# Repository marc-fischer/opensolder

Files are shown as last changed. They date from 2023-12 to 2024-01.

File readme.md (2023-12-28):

# Marcs OpenSolder
Fully open source JBC T245-compatible soldering station and tool holder, forked from [howie-j's opensolder](https://github.com/howie-j/opensolder)


## Introduction
When looking to buy a genuine JBC station to replace my dated ERSA icon Pico I've came across howie-j's opensolder. That was already pretty close to my requirements, so i forked this repo. 

## Goals:
- _T12 clone_ form factor that does not take up valuable bench space
- Optional USB connection to PID tune and compensate offsets
- Add a tag-connect debug connector 
- Add a I2C to the breakout to be able to extend functionality afterwards (ie. desolder station)
- JBC T245 tip compatibility, with similar performance to the original station
- QoL features that the CDB station have, like auto standby, tip remover, holder, tip cleaner etc.
- Simple design using cheap off-the-shelf parts
- A compact handpiece stand with these features:
	- Detection when the handpiece is in the tool holder (auto standby)
	- Detection when you're about to swap tips (cut power)
	- Integrated tip remover, tip storage, tip cleaner and a soldering wire spool holder
	- Simple to build

## Design Specifications
- 24V toroidal transformer
- Zero Crossing AC switching
- OLED display and rotary encoder for adjusting temperature
- Compact and low profile design
- Super fast heatup time (~4s)
- Hardware should be mostly 3D printable, and easy to build using regular tools

## Station
  
The station is built in a Hammond enclosure, with a center mounted transformer. The PCB is mounted to the custom front panel, and all 230VAC connections is in the rear of the chassis.
There is two connectors on the rear panel, one for connecting to the stand, and an optional ST-link connector for firmware upgrades.

## Stand
  
The stand is made of 3D-printed parts, a genuine JBC tool holder, a tip remover made from aluminium angle and some fasteners. Most parts can be made from aluminium sheet if that is preferred.

## Schematic
This is the internal connections of the JBC C245 cartridge:  
  

[__The schematic__](https://github.com/howie-j/OpenSolder/raw/main/hardware/schematic.pdf) is divided into three sheets: AC, Analog and MCU.

### AC
The 24VAC input is fused, then connected directly to the tip center pin (5). Switching is done with two N-channel mosfets, driven by a Si8751 isolated gate driver.

Zero cross detection is done with an AC optocoupler, and the current is limited by three 10k resistors (to reduce BOM items). This solution triggers the ZeroCross about 90uS prematurely, and that is compensated for in firmware.

The MCU and thermocouple frontend must be electrically isolated, and a 24V to 5V DCDC PSU module solves that problem. The DCDC-supply is preregulated with a 24V linear regulator, and post-regulated to 3.3V with a LDO. This power supply chain is in need of some simplification, but the components are few and cheap, and it works great for now.

### Analog
The thermocouple signal is amplified with a MAX4238 chopper opamp, with a fairly arbitrary amplification of 221, since temperature calibration is done in firmware anyway. No negative supply rail means the thermocouple can't sense lower temperatures than room temp, but that's not needed for a soldering station.

Long handpiece wires means lots of crosstalk, so a pair of diodes clamps the thermocouple input at Vf. The MCU pin _TIP_CLAMP_ is driven low when power is applied to the handpiece, to clamp noise on the opamp input. When its time to measure tip temperature, the pin is set to input, and a delay waits for the RC filter to stabilize.

To sense if there is a tip cartridge in the handpiece, _TIP_CHECK_ is driven high. The low impedance of the thermocouple + heater (a few Ω's) will create a very low voltage drop. If the tip is removed, the Vf of the input protection diode will drive _THERMOCOUPLE_ADC_ close to 3.3V.

### MCU
A STM32F072 is used since I have a few of them in stock, but almost any STM32 could be adapted to work. To sense PCB temperature (and for cold junction compensation), an I2C temp sensor is added. The MCU might have an internal temperature sensor, but  have not looked into that yet.

The rotary encoder and handpiece stand inputs are filtered using plain RC filters. This, combined with the input hysteresis, removes most input noise. The TIM encoder inputs also have additional filtering and FSM redundancy.

## PCB
[___Check out this interactive BOM___](http://htmlpreview.github.io/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)

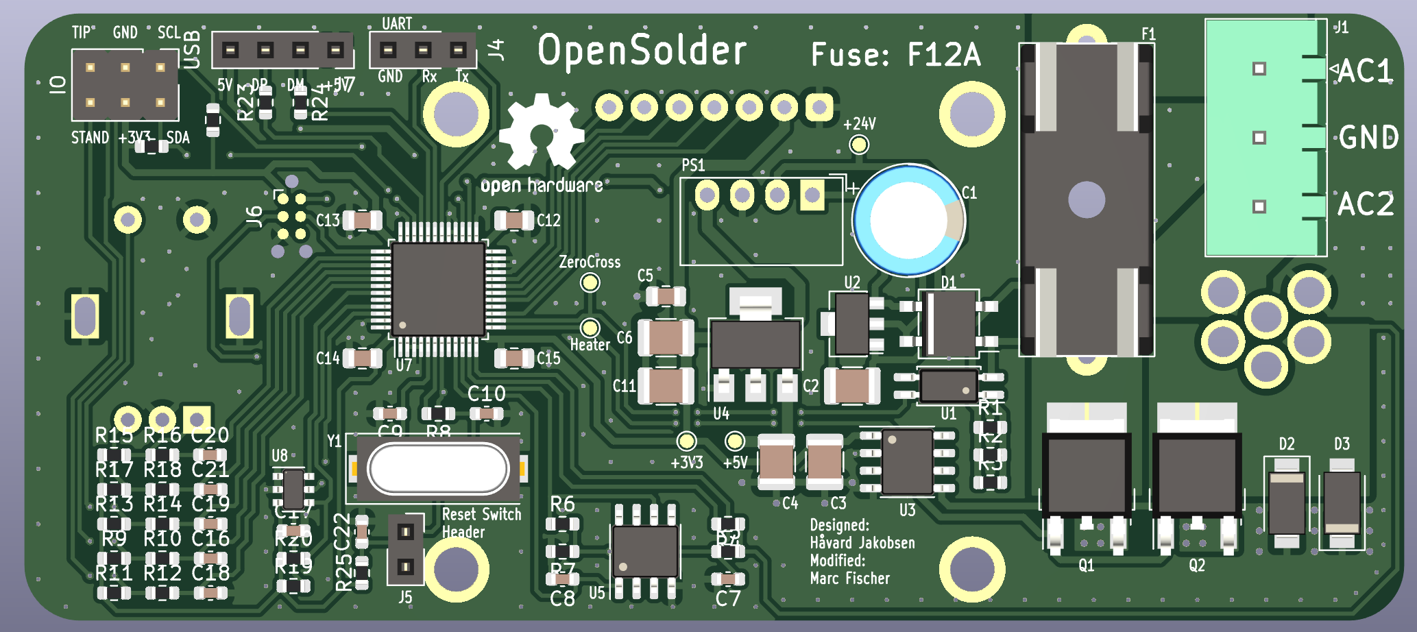
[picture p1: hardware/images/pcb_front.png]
  
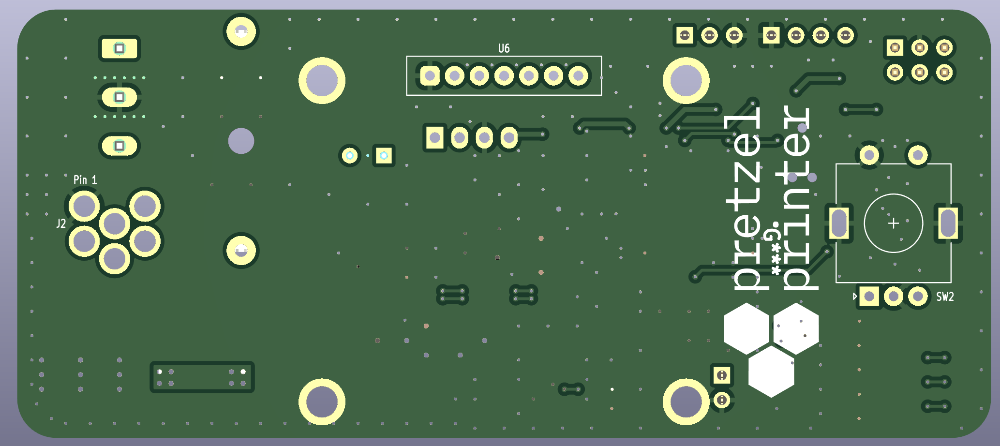
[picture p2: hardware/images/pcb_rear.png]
  
The PCB is quite low density, uses 0603 SMD components and is fully hand solderable with a microscope. Connections to the rear connectors (stand and I2C-2 breakout) is done via a 6-pin IDC connector, so no crimping of tiny connector pins are necessary. The PCB is mounted to the front panel via the rotary encoder and the handpiece connector.

## Firmware
The firmware is simple and functional, and uses a modified hysteresis temperature controller that is very fast but has some initial overshoot. Currently all default values are set in _opensolder.h_, and are reset when the station is powered off.

### TODO
Nothing is currently missing for regular functionality. However some features would be cool to have:

- More accurate temp control (PID or other controller)
- User changeable default values
- Menu for changing default values
- Better looking UI

## Links and Sources
[The unisolder project](https://github.com/sparkybg/UniSolder-5.2) 
[Marco Reps](https://youtu.be/GYIiOkr6x9o) 
[foldvarid93's JBC Soldering Station](https://github.com/foldvarid93/JBC_SolderingStation) 
[johnmx's eevblog thread](https://eevblog.com/forum/testgear/jbc-soldering-station-cd-2bc-complete-schematic-analysis/) 
[howie-j's opensolder](https://github.com/howie-j/opensolder)

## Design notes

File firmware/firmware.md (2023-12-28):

# Do not use this firmware. (yet) 

Work in Progress without possibility to test. I'm still waiting for hardware.

### Installation

Install STM32CubeIDE, click "Open project from filesystem" and select the "opensolder" folder.

### Code structure
All cube-generated files are untouched, except for calling opensolder_init() and opensolder_main() in main.c.
- opensolder.c is the "main" file, containing the init calls, superloop and state machine
- opensolder.h contains most constants for easy editing
- tip_temperature.c handles interrupts, does temperature control, adc reading, tip check and such
- gui.c contains all functions to draw graphics to the OLED display

There is a fair bit of comments in the code, and better documentation can be provided if requested. If you have a question or see an issue, just open an issue in this repo.

The tip temperature (heater control) loop happens interrupt-based on a AC alternation (zero-cross). The two-point regulator disables power and enables power depending if the iron should heat or not.

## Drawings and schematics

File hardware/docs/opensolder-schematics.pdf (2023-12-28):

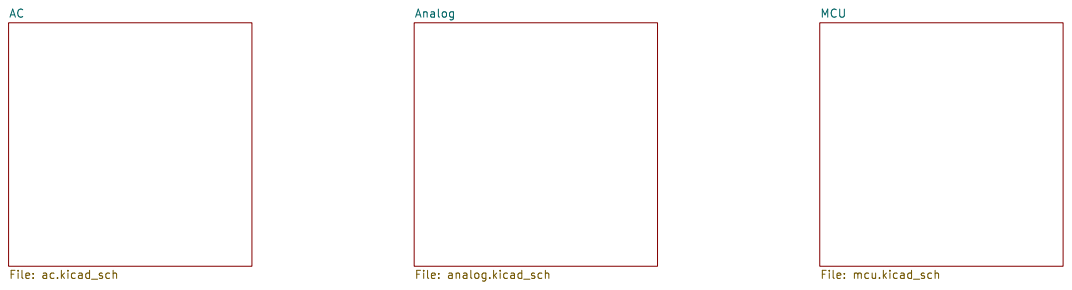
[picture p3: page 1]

File: mcu.kicad_sch Analog File: analog.kicad_sch

Id: 1/4 Title: Marcs OpenSolder Station Schematic

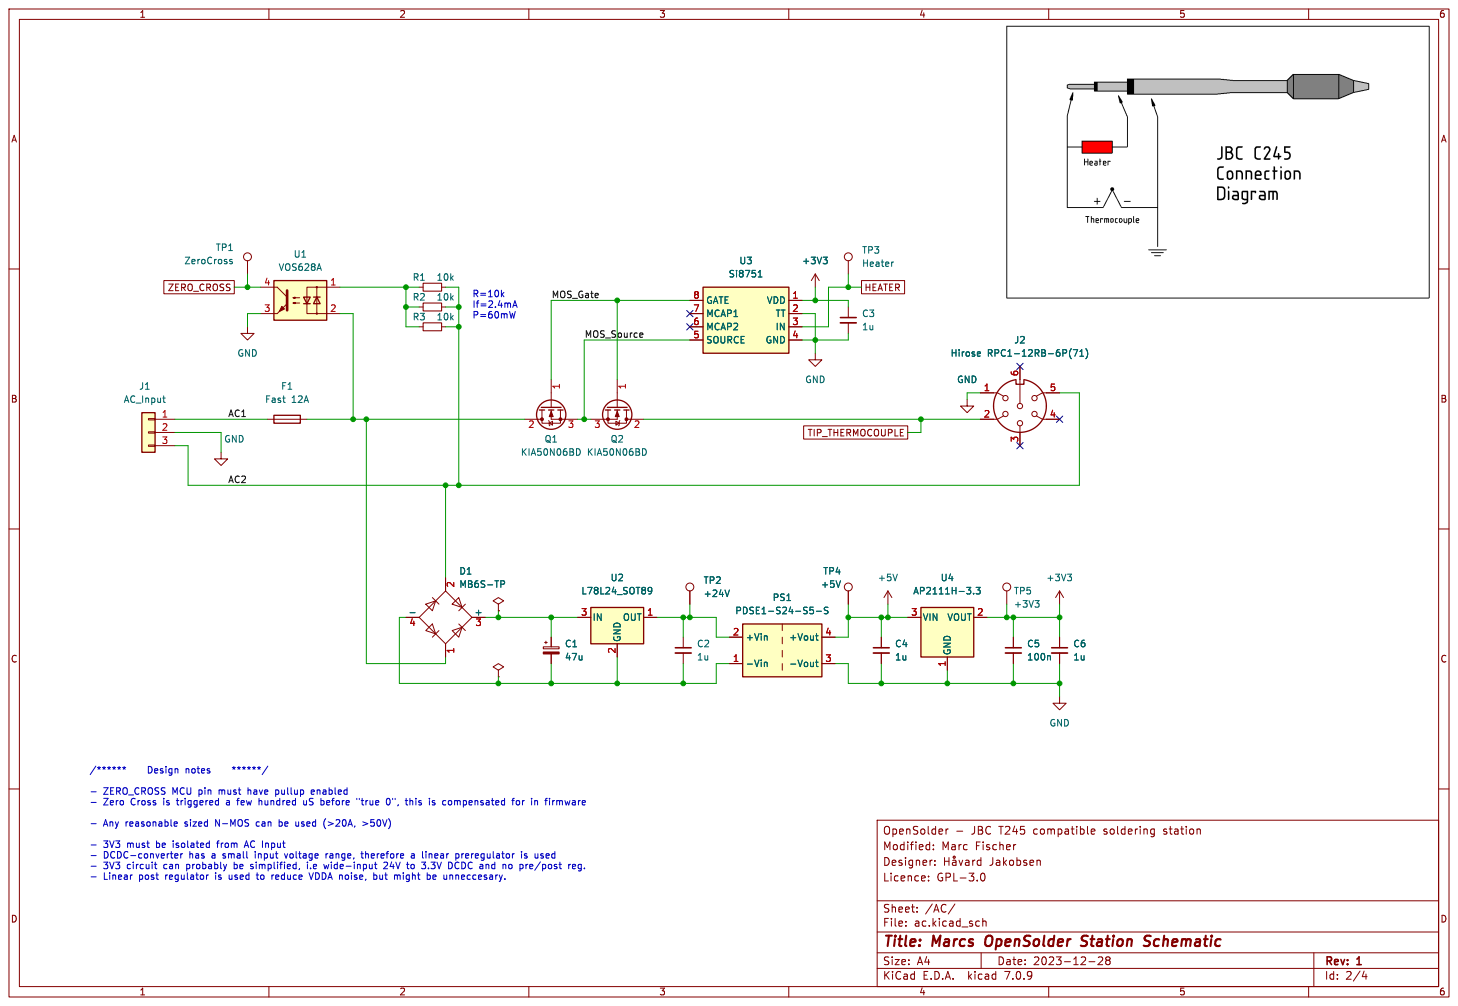
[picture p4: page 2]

1 VOUT 2 VIN 3 U4 AP2111H-3.3 R1 10k TP1 ZeroCross GND GND GND

Id: 2/4 Title: Marcs OpenSolder Station Schematic

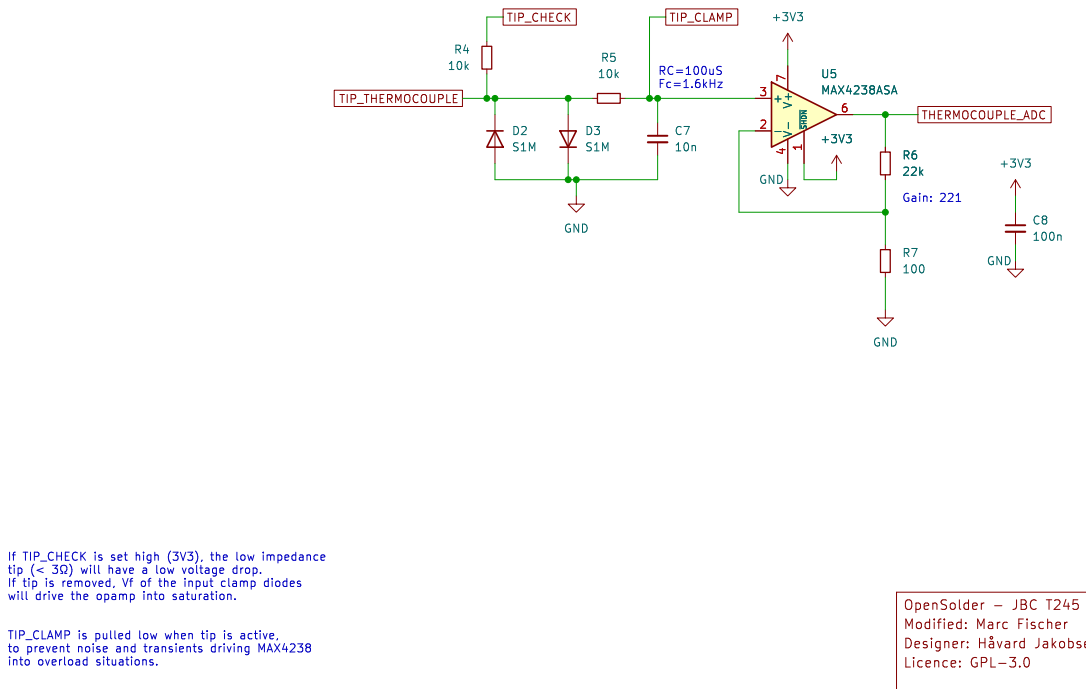
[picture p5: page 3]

If TIP_CHECK is set high (3V3), the low impedance
tip (< þÿ3©) will have a low voltage drop.
If tip is removed, Vf of the input clamp diodes will drive the opamp into saturation. TIP_CLAMP is pulled low when tip is active,

Id: 3/4 Title: Marcs OpenSolder Station Schematic

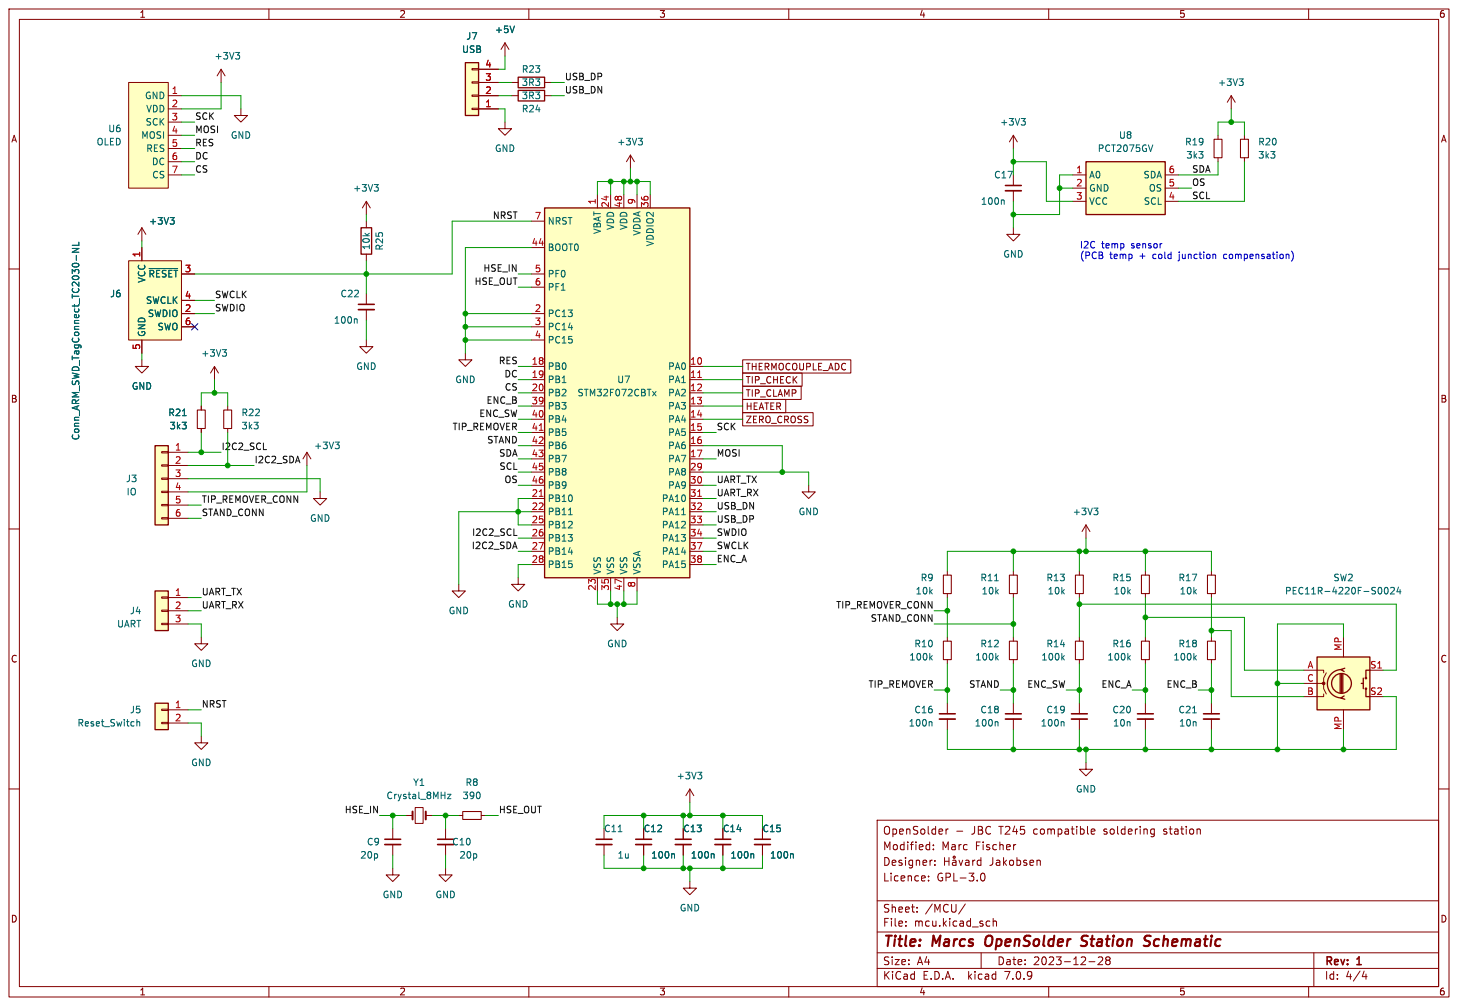
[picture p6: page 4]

1 PA0 10 PA1 11 PA2 12 PA3 13 PA4 14 PA5 15 PA6 16 PA7 17 PB0 18 PB1 19 PC13 2 PB2 20 PB10 21 PB11 22 VSS 23 VDD 24 PB12 25 PB13 26 PB14 27 PB15 28 PA8 29 PC14 3 PA9 30 PA10 31 PA11 32 PA12 33 PA13 34 VSS 35 VDDIO2 36 PA14 37 PA15 38 PB3 39 PC15 4 PB4 40 PB5 41 PB6 42 PB7 43 BOOT0 44 PB8 45 PB9 46 VSS 47 VDD 48 PF0 5 PF1 6 NRST 7 VSSA

1 SWDIO 2 ~{RESET}3 SWCLK 4 GND

Id: 4/4 Title: Marcs OpenSolder Station Schematic

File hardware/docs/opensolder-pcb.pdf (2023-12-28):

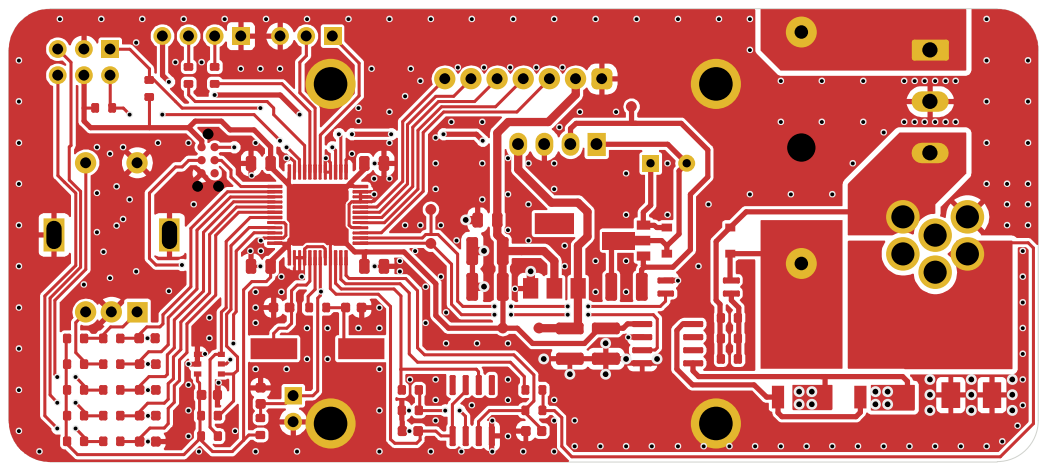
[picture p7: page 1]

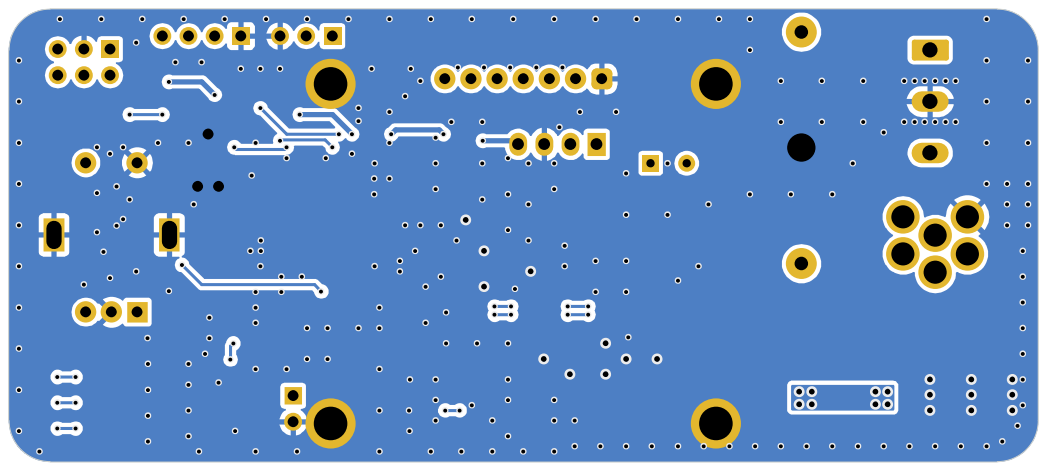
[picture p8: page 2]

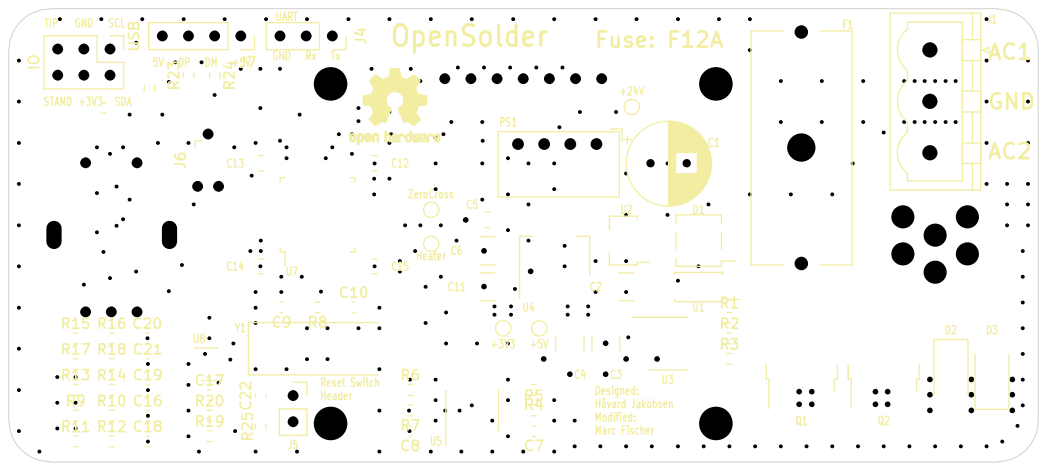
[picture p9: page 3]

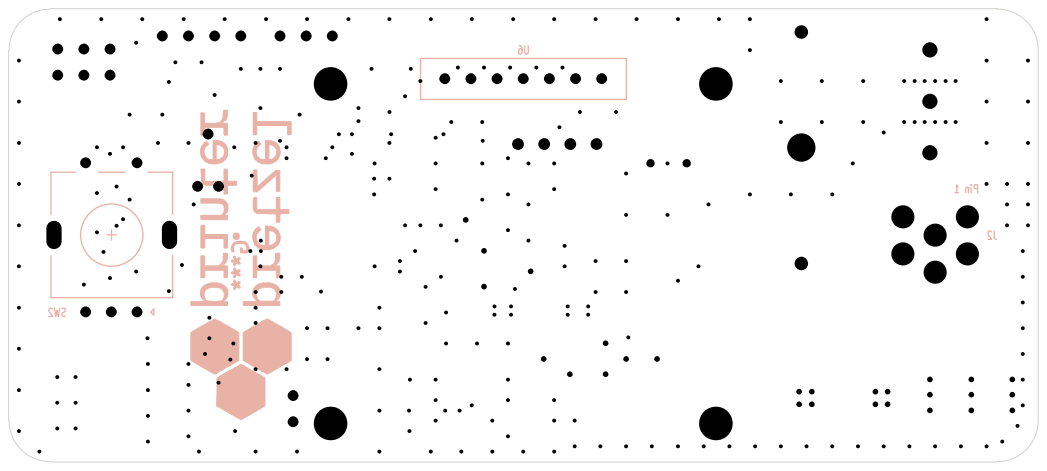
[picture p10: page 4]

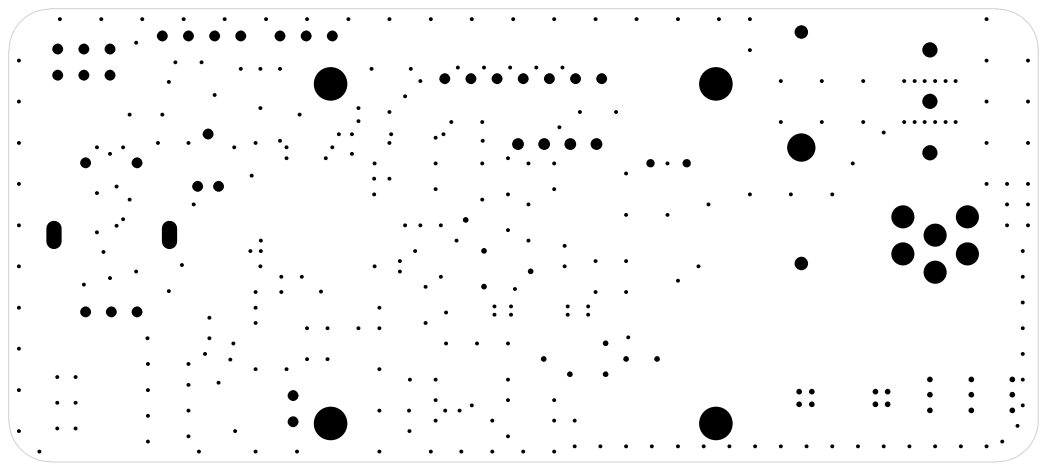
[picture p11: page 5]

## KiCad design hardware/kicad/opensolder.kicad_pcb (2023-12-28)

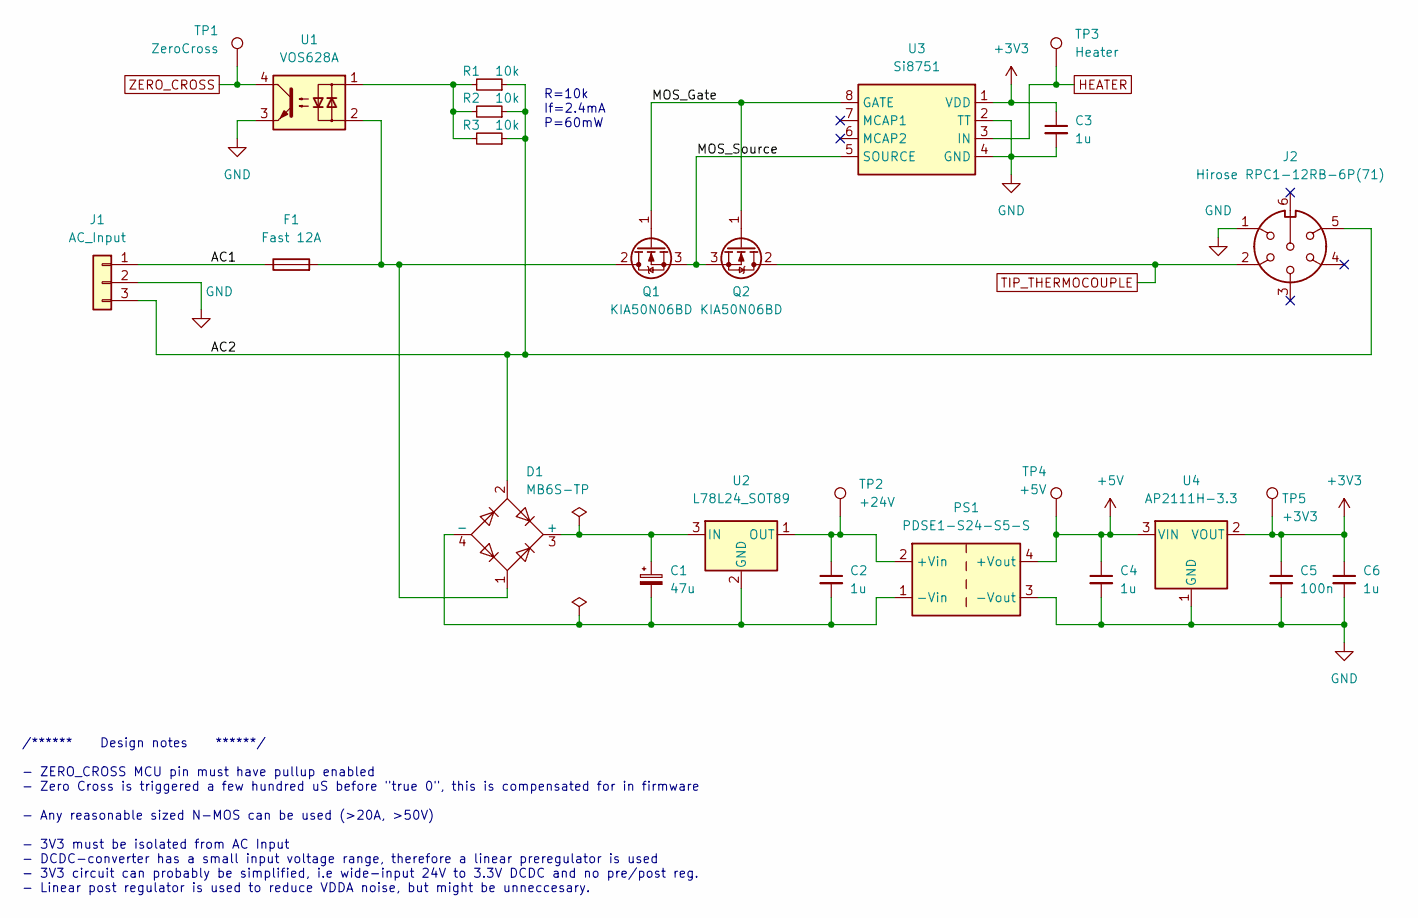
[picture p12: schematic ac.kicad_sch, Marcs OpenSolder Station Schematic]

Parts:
C1: 47u; CP_Radial_D8.0mm_P3.50mm
C2, C3, C4, C6: 1u; C_1210_3225Metric
C5: 100n; C_0805_2012Metric
D1: MB6S-TP; TO-269AA
F1: Fast 12A; Fuseholder_Cylinder-5x20mm_Schurter_0031_8201_Horizontal_Op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
J1: AC_Input; PhoenixContact_MSTBVA_2,5_3-G_1x03_P5.00mm_Vertical
J2: Hirose RPC1-12RB-6P(71); Hirose_RPC1
PS1: PDSE1-S24-S5-S; PDSE1_DCDC
Q1, Q2: KIA50N06BD; TO-252-2
R1, R2, R3: 10k; R_0603_1608Metric
TP1: ZeroCross; TestPoint_Pad_D1.0mm
TP2: +24V; TestPoint_Pad_D1.0mm
TP3: Heater; TestPoint_Pad_D1.0mm
TP4: +5V; TestPoint_Pad_D1.0mm
TP5: +3V3; TestPoint_Pad_D1.0mm
U1: VOS628A; SOP-4_4.4x2.6mm_P1.27mm
U2: L78L24_SOT89; SOT-89-3
U3: Si8751; SOIC-8_3.9x4.9mm_P1.27mm
U4: AP2111H-3.3; SOT-223

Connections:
+3V3: C3.1, C5.1, C6.1, TP5.1, U3.1 (VDD), U4.2 (VOUT); also elsewhere on the board
+5V: C4.1, PS1.4 (+Vout), TP4.1, U4.3 (VIN); also elsewhere on the board
/AC/AC1: F1.1, J1.1
/AC/AC2: D1.2, J1.3, J2.5, R1.1, R2.1, R3.1
/AC/MOS_Gate: Q1.1 (G), Q2.1 (G), U3.8 (GATE)
/AC/MOS_Source: Q1.3 (S), Q2.3 (S), U3.5 (SOURCE)
GND: C3.2, C4.2, C5.2, C6.2, J1.2, J2.1, PS1.3 (-Vout), U1.3, U3.2 (TT), U3.4 (GND), U4.1 (GND); also elsewhere on the board
HEATER: TP3.1, U3.3 (IN); also elsewhere on the board
unnamed: C1.1, D1.3 (+), U2.3 (IN)
unnamed: C1.2, C2.2, D1.4 (-), PS1.1 (-Vin), U2.2 (GND)
unnamed: C2.1, PS1.2 (+Vin), TP2.1, U2.1 (OUT)
unnamed: D1.1, F1.2, Q1.2 (D), U1.2
unnamed: R1.2, R2.2, R3.2, U1.1
TIP_THERMOCOUPLE: J2.2, Q2.2 (D); also elsewhere on the board
ZERO_CROSS: TP1.1, U1.4; also elsewhere on the board

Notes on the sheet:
R=10k If=2.4mA P=60mW
/****** Design notes ******/ - ZERO_CROSS MCU pin must have pullup enabled - Zero Cross is triggered a few hundred uS before "true 0", this is compensated for in firmware - Any reasonable sized N-MOS can be used (>20A, >50V) - 3V3 must be isolated from AC Input - DCDC-converter has a small input vo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

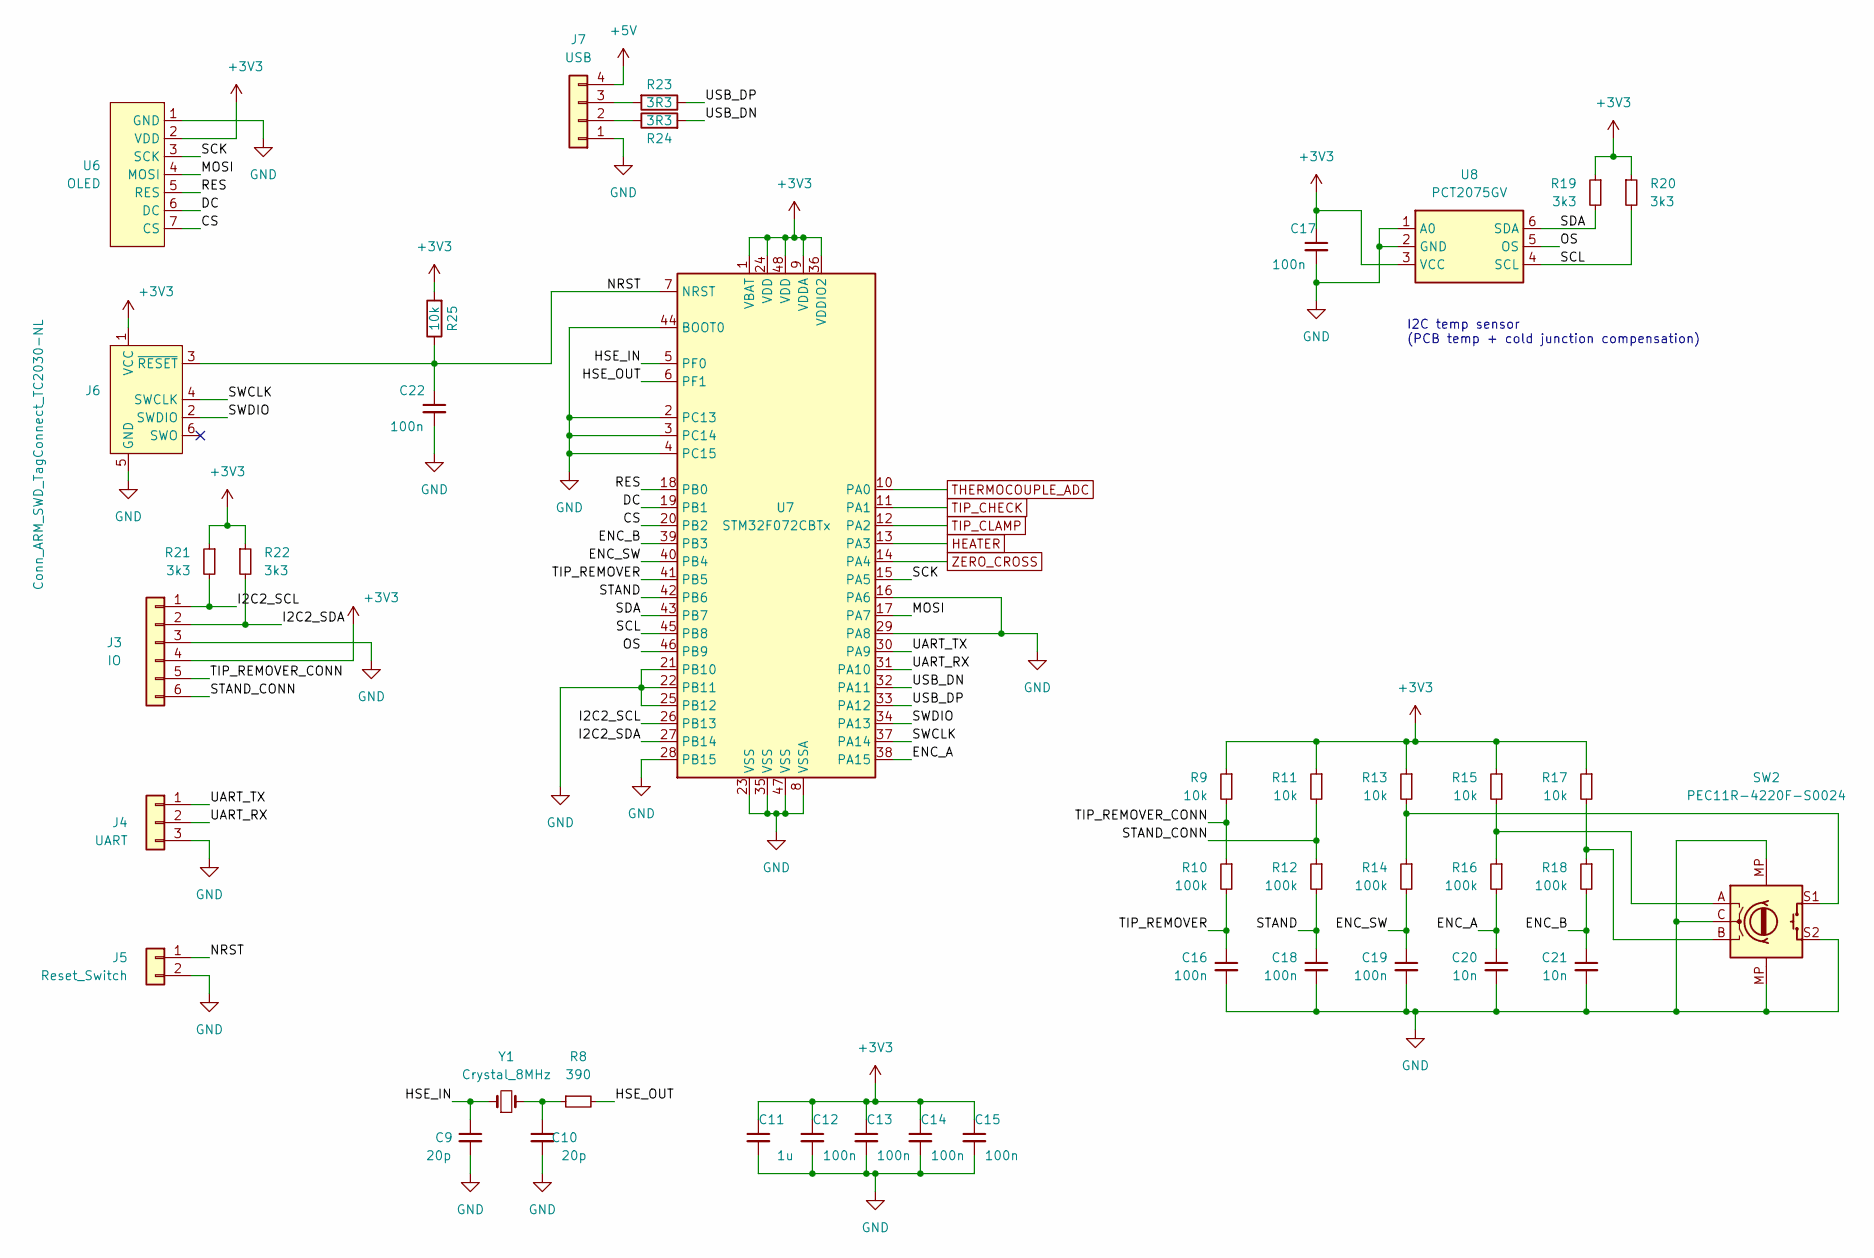
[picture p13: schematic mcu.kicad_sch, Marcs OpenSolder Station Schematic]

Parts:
C9, C10: 20p; C_0603_1608Metric
C11: 1u; C_1210_3225Metric
C12, C13, C14, C15: 100n; C_0805_2012Metric
C16, C17, C18, C19, C22: 100n; C_0603_1608Metric
C20, C21: 10n; C_0603_1608Metric
J3: IO; PinHeader_2x03_P2.54mm_Vertical
J4: UART; PinSocket_1x03_P2.54mm_Vertical
J5: Reset_Switch; PinSocket_1x02_P2.54mm_Vertical
J6: Conn_ARM_SWD_TagConnect_TC2030-NL; Tag-Connect_TC2030-IDC-NL_2x03_P1.27mm_Vertical
J7: USB; PinSocket_1x04_P2.54mm_Vertical
R8: 390; R_0603_1608Metric
R9, R11, R13, R15, R17, R25: 10k; R_0603_1608Metric
R10, R12, R14, R16, R18: 100k; R_0603_1608Metric
R19, R20, R21, R22: 3k3; R_0603_1608Metric
R23, R24: 3R3; R_0603_1608Metric
SW2: PEC11R-4220F-S0024; RotaryEncoder_PEC11R_PEC12R
U6: OLED; OLED_SSD1306_SPI_1.54
U7: STM32F072CBTx; LQFP-48_7x7mm_P0.5mm
U8: PCT2075GV; TSOP-6_1.65x3.05mm_P0.95mm
Y1: Crystal_8MHz; Crystal_SMD_HC49-SD

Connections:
+3V3: C11.1, C12.1, C13.1, C14.1, C15.1, C17.1, J3.4, J6.1 (VCC), R9.1, R11.1, R13.1, R15.1, R17.1, R19.1, R20.1, R21.1, R22.1, R25.2, U6.2 (VDD), U7.1 (VBAT), U7.9 (VDDA), U7.24 (VDD), U7.36 (VDDIO2), U7.48 (VDD), U8.3 (VCC); also elsewhere on the board
+5V: J7.4; also elsewhere on the board
/MCU/CS: U6.7 (CS), U7.20 (PB2)
/MCU/DC: U6.6 (DC), U7.19 (PB1)
/MCU/ENC_A: C20.1, R16.2, U7.38 (PA15)
/MCU/ENC_B: C21.1, R18.2, U7.39 (PB3)
/MCU/ENC_SW: C19.1, R14.2, U7.40 (PB4)
/MCU/HSE_IN: C9.1, U7.5 (PF0), Y1.1
/MCU/HSE_OUT: R8.2, U7.6 (PF1)
/MCU/I2C2_SCL: J3.1, R21.2, U7.26 (PB13)
/MCU/I2C2_SDA: J3.2, R22.2, U7.27 (PB14)
/MCU/MOSI: U6.4 (MOSI), U7.17 (PA7)
/MCU/NRST: C22.1, J5.1, J6.3 (~RESET), R25.1, U7.7 (NRST)
/MCU/OS: U7.46 (PB9), U8.5 (OS)
/MCU/RES: U6.5 (RES), U7.18 (PB0)
/MCU/SCK: U6.3 (SCK), U7.15 (PA5)
/MCU/SCL: R20.2, U7.45 (PB8), U8.4 (SCL)
/MCU/SDA: R19.2, U7.43 (PB7), U8.6 (SDA)
/MCU/STAND: C18.1, R12.2, U7.42 (PB6)
/MCU/STAND_CONN: J3.6, R11.2, R12.1
/MCU/SWCLK: J6.4 (SWCLK), U7.37 (PA14)
/MCU/SWDIO: J6.2 (SWDIO), U7.34 (PA13)
/MCU/TIP_REMOVER: C16.1, R10.2, U7.41 (PB5)
/MCU/TIP_REMOVER_CONN: J3.5, R9.2, R10.1
/MCU/UART_RX: J4.2, U7.31 (PA10)
/MCU/UART_TX: J4.1, U7.30 (PA9)
/MCU/USB_DN: R24.2, U7.32 (PA11)
/MCU/USB_DP: R23.1, U7.33 (PA12)
GND: C9.2, C10.2, C11.2, C12.2, C13.2, C14.2, C15.2, C16.2, C17.2, C18.2, C19.2, C20.2, C21.2, C22.2, J3.3, J4.3, J5.2, J6.5 (GND), J7.1, SW2.C, SW2.MP, SW2.S2, U6.1 (GND), U7.2 (PC13), U7.3 (PC14), U7.4 (PC15), U7.8 (VSSA), U7.16 (PA6), U7.21 (PB10), U7.22 (PB11), U7.23 (VSS), U7.25 (PB12), U7.28 (PB15), U7.29 (PA8), U7.35 (VSS), U7.44 (BOOT0), U7.47 (VSS), U8.1 (A0), U8.2 (GND); also elsewhere on the board
HEATER: U7.13 (PA3); also elsewhere on the board
unnamed: C10.1, R8.1, Y1.2
unnamed: J7.2, R24.1
unnamed: J7.3, R23.2
unnamed: R13.2, R14.1, SW2.S1
unnamed: R15.2, R16.1, SW2.A
unnamed: R17.2, R18.1, SW2.B
THERMOCOUPLE_ADC: U7.10 (PA0); also elsewhere on the board
TIP_CHECK: U7.11 (PA1); also elsewhere on the board
TIP_CLAMP: U7.12 (PA2); also elsewhere on the board
ZERO_CROSS: U7.14 (PA4); also elsewhere on the board

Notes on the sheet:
I2C temp sensor (PCB temp + cold junction compensation)

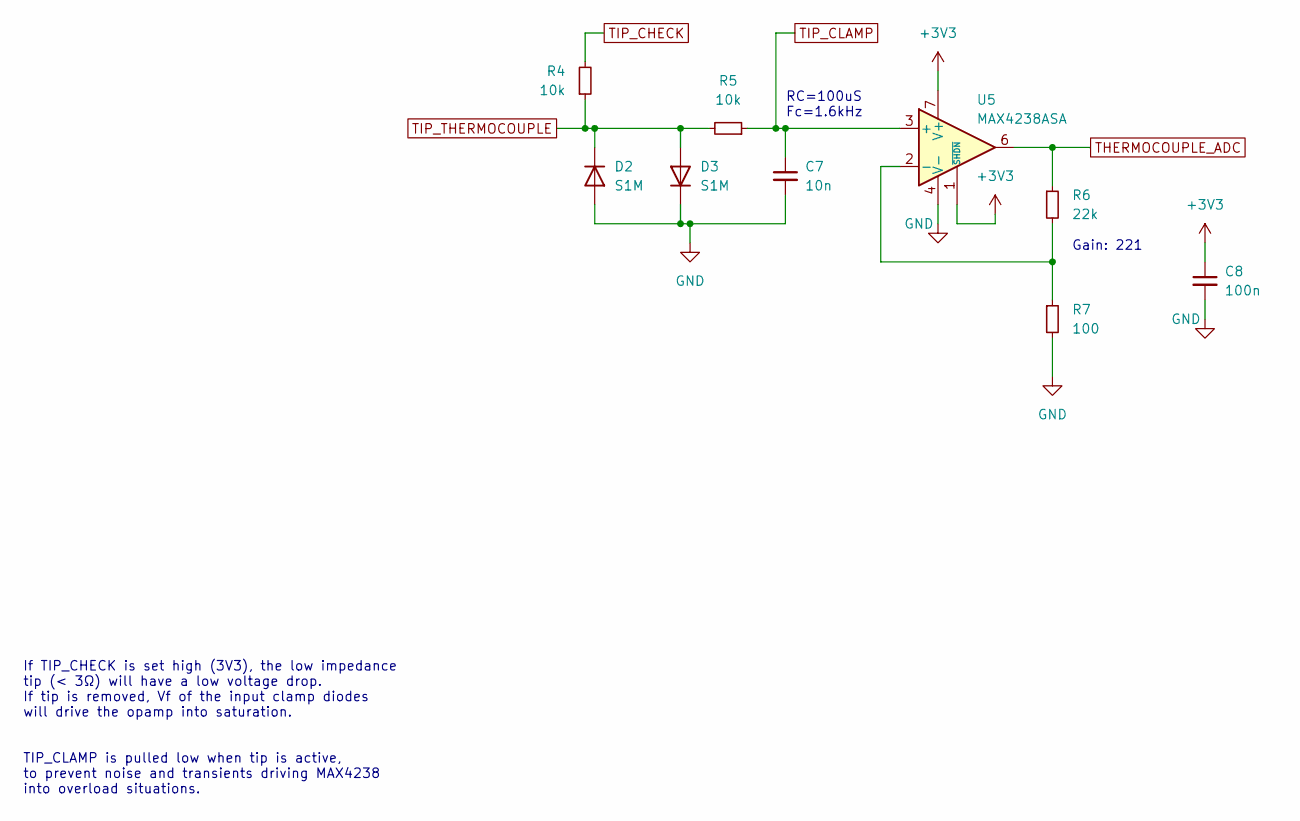
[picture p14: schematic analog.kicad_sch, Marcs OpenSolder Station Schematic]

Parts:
C7: 10n; C_0603_1608Metric
C8: 100n; C_0603_1608Metric
D2, D3: S1M; D_SMA
R4, R5: 10k; R_0603_1608Metric
R6: 22k; R_0603_1608Metric
R7: 100; R_0603_1608Metric
U5: MAX4238ASA; SOIC-8_3.9x4.9mm_P1.27mm

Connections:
+3V3: C8.1, U5.1 (~SHDN), U5.7 (V+); also elsewhere on the board
GND: C7.2, C8.2, D2.2 (A), D3.1 (K), R7.2, U5.4 (V-); also elsewhere on the board
unnamed: R6.2, R7.1, U5.2 (-)
THERMOCOUPLE_ADC: R6.1, U5.6; also elsewhere on the board
TIP_CHECK: R4.2; also elsewhere on the board
TIP_CLAMP: C7.1, R5.1, U5.3 (+); also elsewhere on the board
TIP_THERMOCOUPLE: D2.1 (K), D3.2 (A), R4.1, R5.2; also elsewhere on the board

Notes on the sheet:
Gain: 221
RC=100uS Fc=1.6kHz
If TIP_CHECK is set high (3V3), the low impedance tip (< 3Ω) will have a low voltage drop. If tip is removed, Vf of the input clamp diodes will drive the opamp into saturation. TIP_CLAMP is pulled low when tip is active, to prevent noise and transients driving MAX4238 into overload situations.

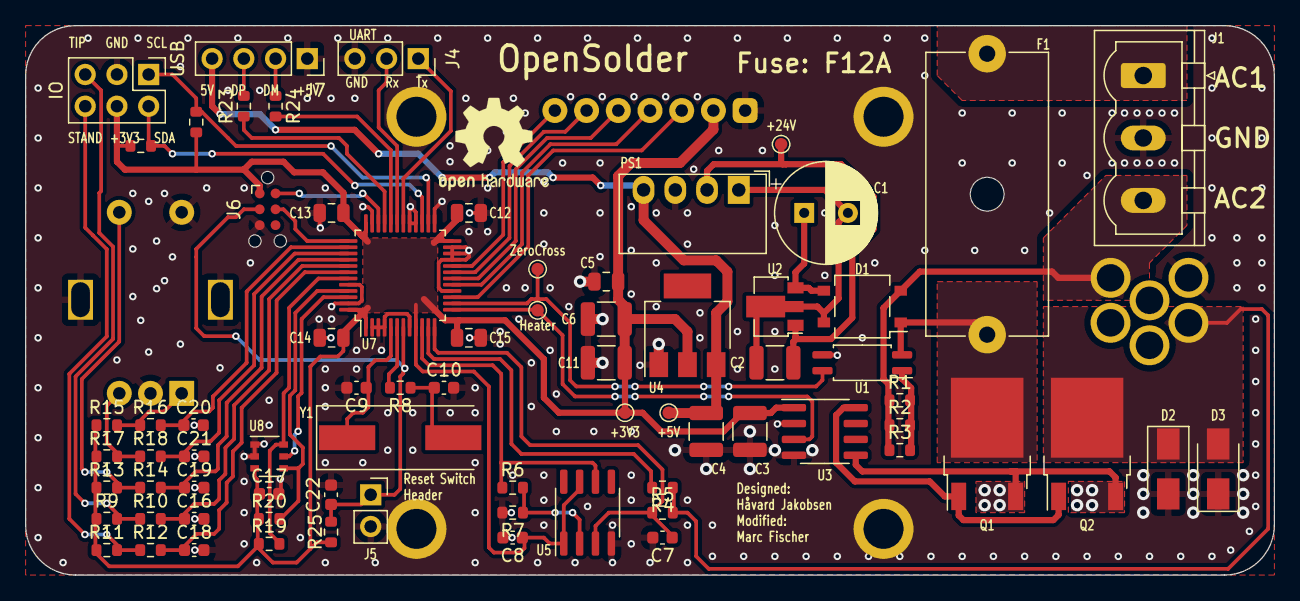
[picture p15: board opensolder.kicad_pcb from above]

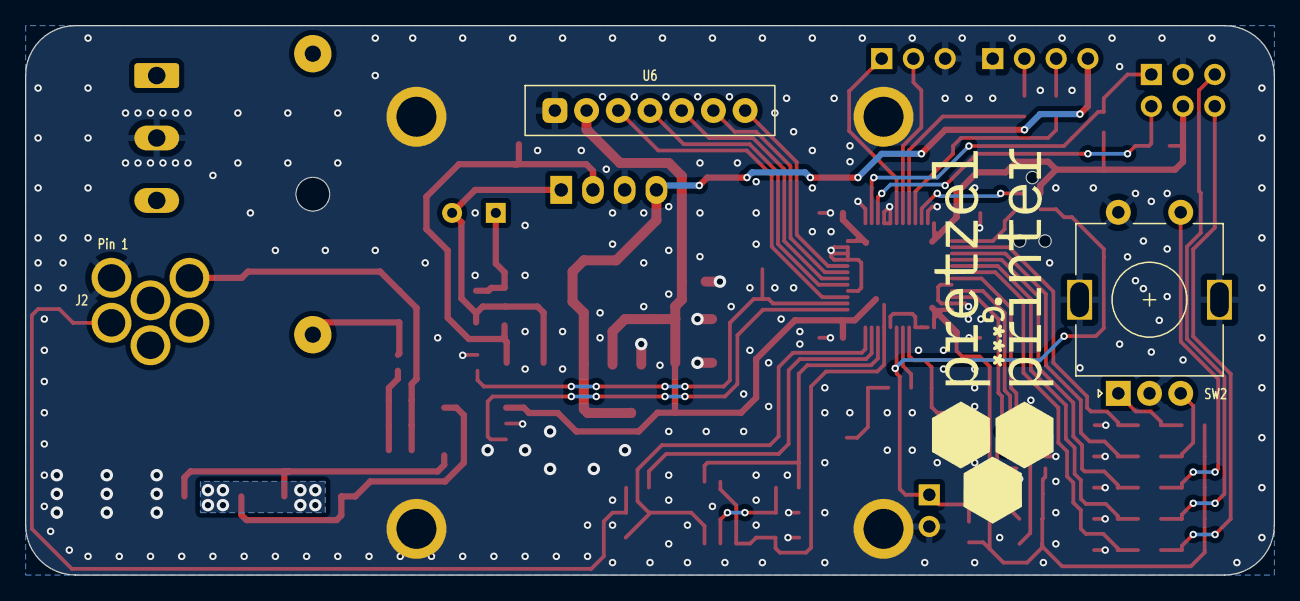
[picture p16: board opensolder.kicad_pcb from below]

Board: 2 copper layers, 100.0 x 44.0 mm, 76 parts (3 on the bottom side), 51 nets.

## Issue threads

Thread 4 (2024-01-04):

Implement Safety Functionality

marc-fischer, 2024-01-04:
Implement safety functionality, i.e. timeouts, overheat checks in low level code,
Implement the Watchdog-Timer

Objective - don't burn my house down when forgetting to power off the unit

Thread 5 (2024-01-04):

Implement a PID algorithm and PID tuning functionality

marc-fischer, 2024-01-04:
Target is to improve initial overshooting when heating up from cold.

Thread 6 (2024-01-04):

Add persistant storage

marc-fischer, 2024-01-04:
To implement a on-screen menu, setpoint saving, PID tuning.. a persistant storage is required.
marcs-opensolder pcb does not have a footprint for an EEPROM.

Consider
a) add an I2C eeprom to the i2c extension header
b) backpack-solder a EEPROM chip to PCB temp sensor (could have negative influences on temperature readings)
c) add a SD card to display SPI port - maybe overkill to store temp values.

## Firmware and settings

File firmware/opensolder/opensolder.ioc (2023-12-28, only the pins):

Mcu.UserName=STM32F072CBTx
PA0.GPIO_Label=THERMOCOUPLE_ADC
PA0.Signal=ADC_IN0
PA1.GPIO_Label=TIP_CHECK
PA1.Signal=GPIO_Input
PA10.Signal=USART1_RX
PA11.Signal=USB_DM
PA12.Signal=USB_DP
PA13.Signal=SYS_SWDIO
PA14.Signal=SYS_SWCLK
PA15.GPIO_Label=ENC_A
PA15.Signal=S_TIM2_CH1_ETR
PA2.GPIO_Label=TIP_CLAMP
PA2.Signal=GPIO_Input
PA3.GPIO_Label=HEATER
PA3.Signal=GPIO_Output
PA4.GPIO_Label=ZERO_CROSS
PA4.Signal=GPXTI4
PA5.Signal=SPI1_SCK
PA7.Signal=SPI1_MOSI
PA9.Signal=USART1_TX
PB0.GPIO_Label=RES
PB0.Signal=GPIO_Output
PB1.GPIO_Label=DC
PB1.Signal=GPIO_Output
PB13.Signal=I2C2_SCL
PB14.Signal=I2C2_SDA
PB2.GPIO_Label=CS
PB2.Signal=GPIO_Output
PB3.GPIO_Label=ENC_B
PB3.Signal=S_TIM2_CH2
PB4.GPIO_Label=ENC_SW
PB4.Signal=GPIO_Input
PB5.GPIO_Label=TIP_REMOVER
PB5.Signal=GPIO_Input
PB6.GPIO_Label=STAND
PB6.Signal=GPIO_Input
PB7.Signal=I2C1_SDA
PB8.Signal=I2C1_SCL
PB9.GPIO_Label=OS
PB9.Signal=GPIO_Input
PF0-OSC_IN.Signal=RCC_OSC_IN
PF1-OSC_OUT.Signal=RCC_OSC_OUT

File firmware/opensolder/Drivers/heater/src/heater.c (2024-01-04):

/*
 * heater.c
 *
 *	This file keeps track of the current heater state and does not allow the heater to be turned on if any error state is set
 *
 *  Created on: Dec 28, 2023
 *      Author: marc
 */

#include "../inc/heater.h"

uint8_t heater_driver__current_state = OK;	// state mutex, defining if the heater output is allowed to be switched on

void heater_driver__set_state(uint8_t state){
	heater_driver__current_state = state;
}
uint8_t heater_driver__get_state(void) {
	return heater_driver__current_state;
}

void heater_driver__set_output_on(void) {
	if(heater_driver__current_state == OK) {	// if an error is present, the output is not allowed to turn on
		HAL_GPIO_WritePin(HEATER_GPIO_Port, HEATER_Pin, ON); // Turn heater on
	} else {
		heater_driver__set_output_off();	// Any other case turn the heater off
	}
}
void heater_driver__set_output_off(void) {
	HAL_GPIO_WritePin(HEATER_GPIO_Port, HEATER_Pin, OFF); // Turn heater off (ignores the forbidden flag, OFF can be a safety state)
}

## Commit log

2023-12-28 removed opensolder releases
    [bom.csv]
2023-12-28 ignore kicad-backups folder
2023-12-28 [HW] Add: - Tag Connect Debug connector - USB & I2C breakout - GND pin to UART breakout
    [ac.kicad_sch, analog.kicad_sch, mcu.kicad_sch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]
2023-12-28 [FW]: Move SSD1306 code from core to Drivers
2023-12-28 rename xxx placeholder to zzz to hide todo in STM32cubeide
2023-12-28 [FW]: split temperature handlers for pcb temperature and tip temperature in different files move pcb temperature to driver folder
2023-12-28 [FW]: - Update STM32f0xx HAL - Add USB, timer14, I2C2, UART
2023-12-28 [FW]: - Abstract Tip check to a driver
2023-12-28 [FW]: - Move Tip Clamp functionality to a driver
2023-12-28 [FW]: - Move Heater Function to a driver, add low-level protection to the driver
2023-12-28 [FW]: - Split "temperature.c" to different files: -- tip_thermocouple - handles all measurement related tasks -- timers - handles interrupts and timers -- tip_heater - handles all heating related tas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
2024-01-04 [FW]:
    Move buttons to HID class, add additional timer for HID, move main state machine to opensolder_main loop

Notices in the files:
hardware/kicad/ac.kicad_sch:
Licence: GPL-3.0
